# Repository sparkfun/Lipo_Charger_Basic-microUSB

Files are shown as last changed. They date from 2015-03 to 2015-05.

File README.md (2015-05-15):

SparkFun LiPo Charger Basic - Micro-USB
========================================

SparkFun LiPo Charger Basic - Micro-USB

[*SparkFun LiPo Charger Basic - Micro-USB (PRT-10217)*](https://www.sparkfun.com/products/10217)

The SparkFun LiPo Charger Basic is stripped down of all features and just does one thing well - charge 3.7V LiPo cells at a rate of 500mA. 
It is designed to charge single-cell Li-Ion or Li-Polymer batteries. 
The board incorporates a charging circuit, status LED, connector for your battery (JST-type used in the batteries we carry), and a micro-USB connector. 
A small mounting hole allows this charger to be easily embedded into a project.

Repository Contents
-------------------
* **/Hardware** - Eagle design files (.brd, .sch)
* **/Production** - Production panel files (.brd)

Documentation
--------------
* **[SparkFun Fritzing repo](https://github.com/sparkfun/Fritzing_Parts)** - Fritzing diagrams for SparkFun products.
* **[SparkFun 3D Model repo](https://github.com/sparkfun/3D_Models)** - 3D models of SparkFun products. 

License Information
-------------------
This product is _**open source**_! 

The **hardware** is released under [Creative Commons ShareAlike 4.0 International](https://creativecommons.org/licenses/by-sa/4.0/).

Please use, reuse, and modify these files as you see fit. Please maintain attribution to SparkFun Electronics and release anything derivative under the same license.

Distributed as-is; no warranty is given.

- Your friends at SparkFun.

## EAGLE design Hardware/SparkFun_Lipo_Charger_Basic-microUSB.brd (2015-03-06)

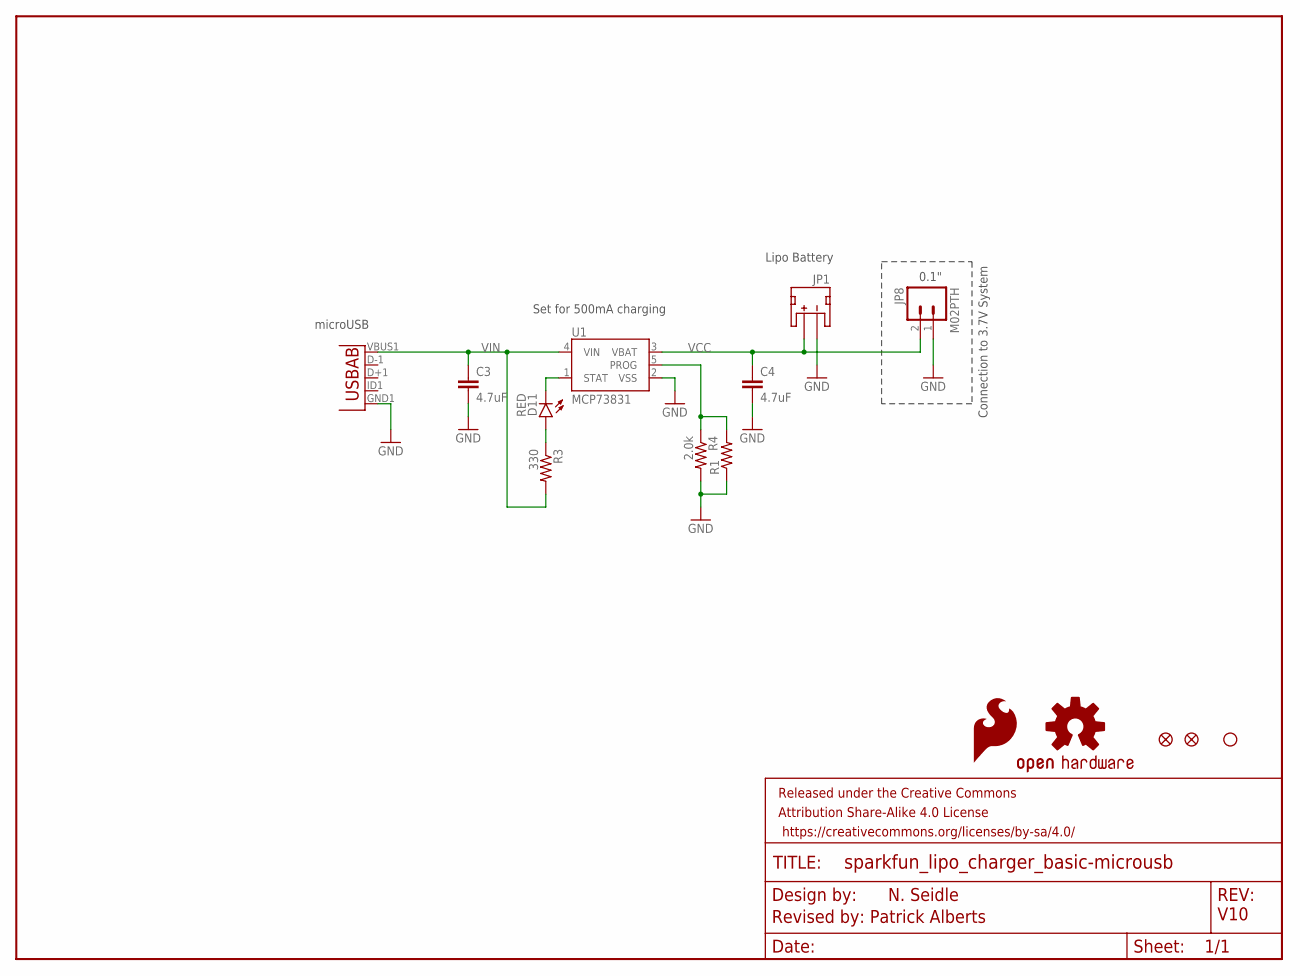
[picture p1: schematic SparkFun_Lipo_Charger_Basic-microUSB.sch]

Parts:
C3, C4: 4.7uF; 0603-CAP
D11: RED; LED-0603
FRAME1: FRAME-LETTER; CREATIVE_COMMONS
JP1: JST; JST-2-SMD
JP2: STAND-OFF
JP3, JP4: FIDUCIAL1X2; FIDUCIAL-1X2
JP8: M02PTH; 1X02
JP9: Micro USB; USB-AB-MICRO-SMD_V03
LOGO1: OSHW-LOGOS; OSHW-LOGO-S
LOGO2: SFE_LOGO_FLAME.1_INCH; SFE_LOGO_FLAME_.1
R1: RESISTORPTH-1/4W-VERT-KIT; AXIAL-0.1EZ
R3: 330; 0603-RES
R4: 2.0k; 0603-RES
U1: MCP73831; SOT23-5

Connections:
GND: C3.2, C4.2, JP1.1 (-), JP8.1, JP9.GND1 (GND), R1.P$1 (1), R4.2, U1.2 (VSS)
unnamed: D11.A, R3.1
PROG: R1.P$2 (2), R4.1, U1.5 (PROG)
STAT: D11.C, U1.1 (STAT)
VCC: C4.1, JP1.2 (+), JP8.2, U1.3 (VBAT)
VIN: C3.1, JP9.VBUS1 (VBUS), R3.2, U1.4 (VIN)

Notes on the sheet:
Set for 500mA charging
Connection to 3.7V System
0.1"
N. Seidle
microUSB
Revised by: Patrick Alberts
V10
Lipo Battery

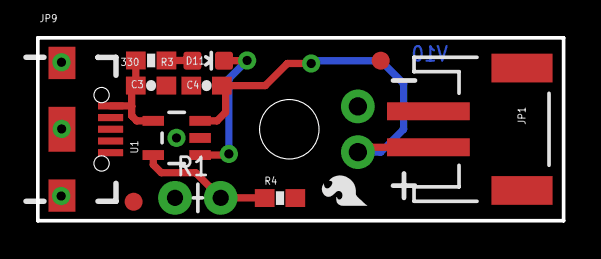
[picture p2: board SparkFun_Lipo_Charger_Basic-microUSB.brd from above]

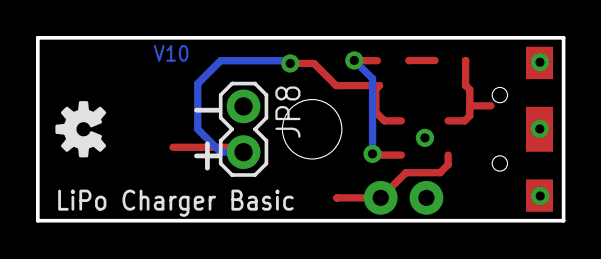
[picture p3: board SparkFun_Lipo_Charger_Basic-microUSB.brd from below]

Board: 2 copper layers, 29.2 x 10.2 mm, 16 parts (2 on the bottom side), 6 nets.

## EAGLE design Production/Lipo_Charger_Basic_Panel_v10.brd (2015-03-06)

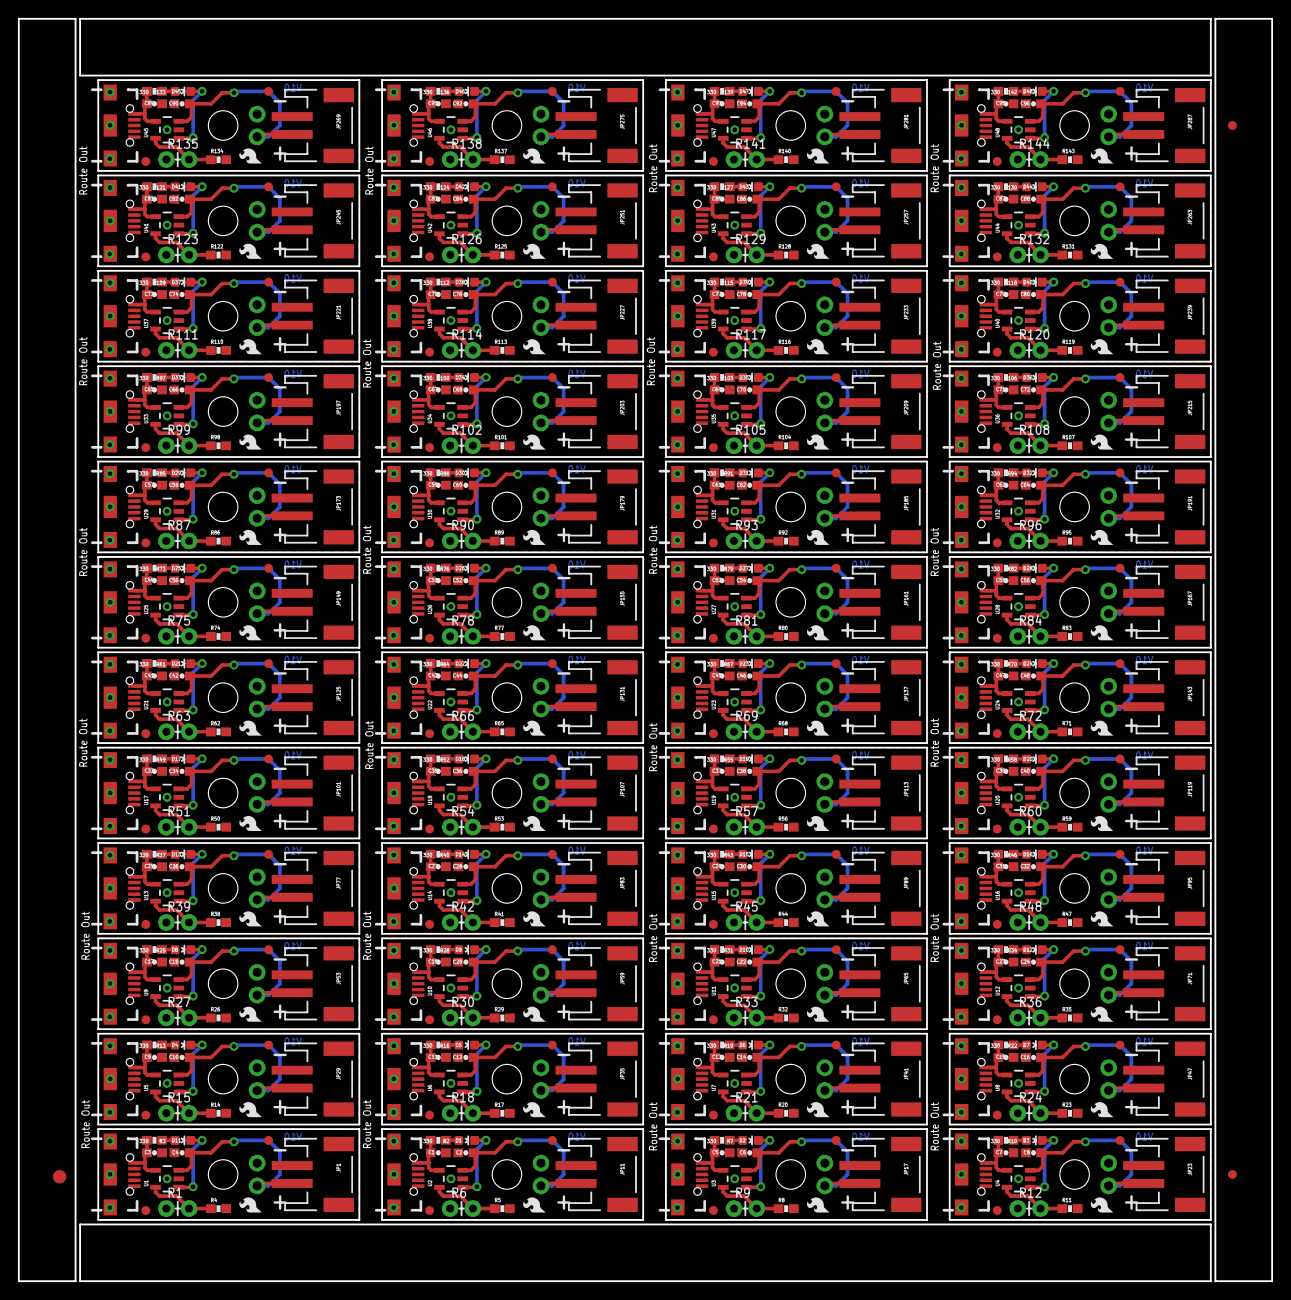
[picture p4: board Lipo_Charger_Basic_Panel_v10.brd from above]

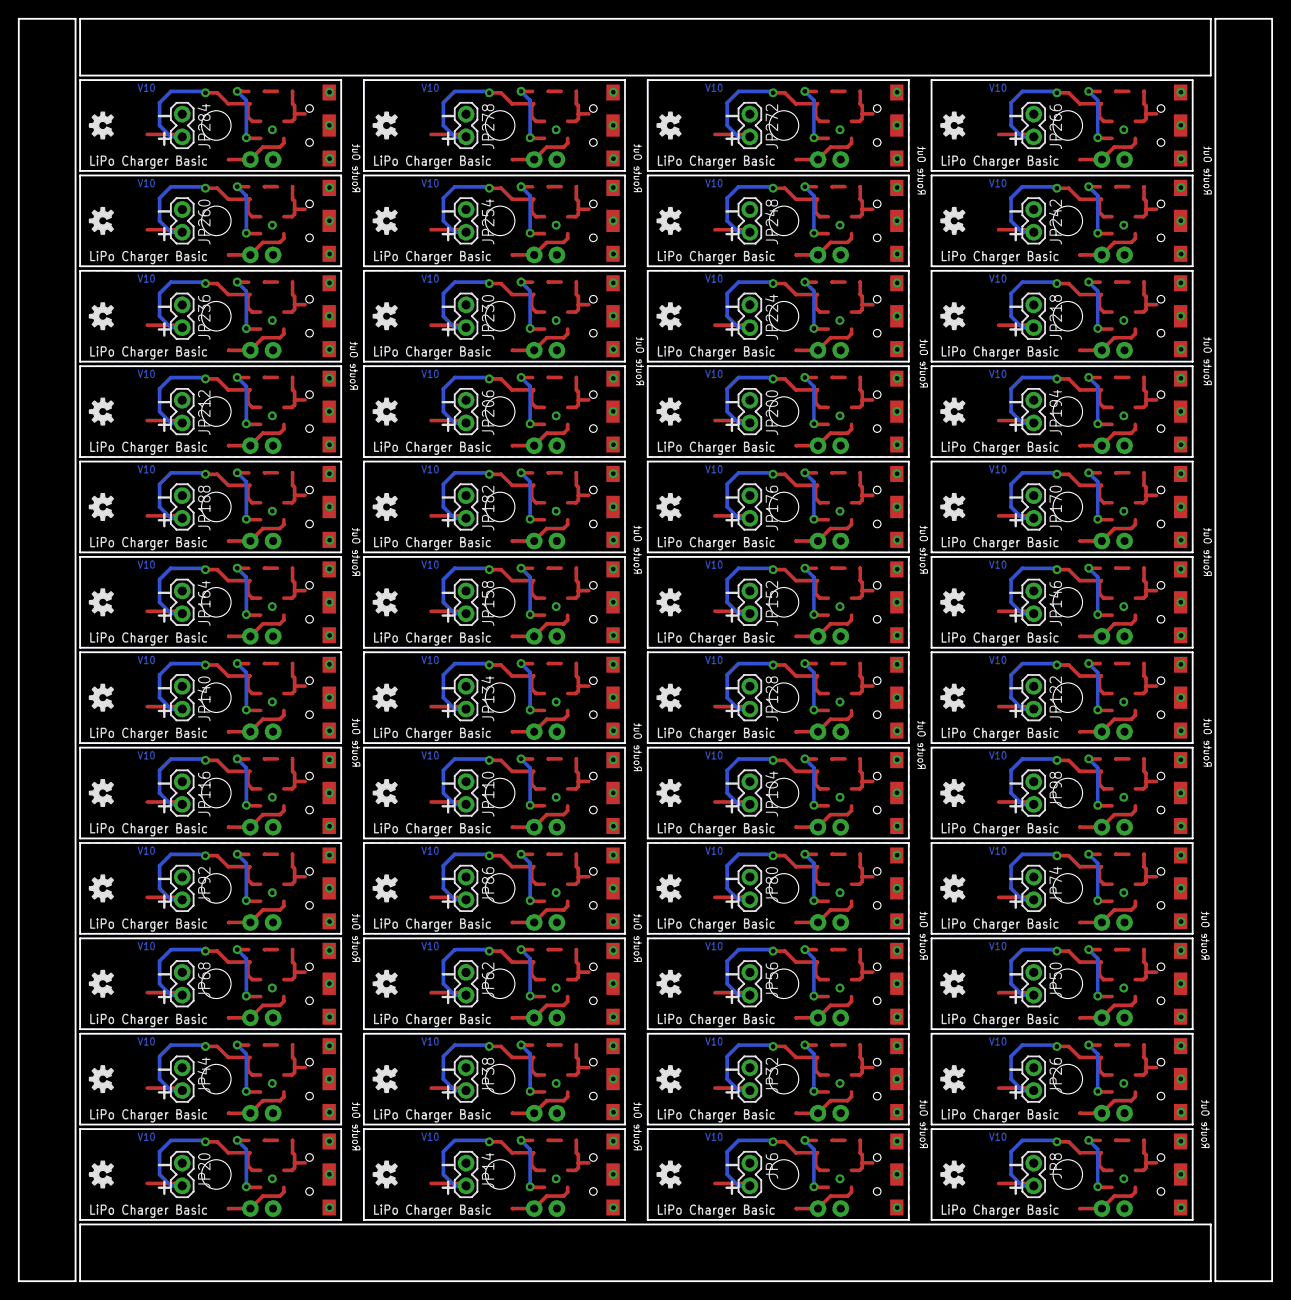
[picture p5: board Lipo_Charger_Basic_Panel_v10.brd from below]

Board: 2 copper layers, 140.2 x 141.2 mm, 723 parts (96 on the bottom side), 288 nets.

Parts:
C1, C2, C3, C4, C5, C6, C7, C8, C9, C10, C11, C12, C13, C14, C15, C16, C17, C18, C19, C20, C21, C22, C23, C24, C25, C26, C27, C28, C29, C30, C31, C32, C33, C34, C35, C36, C37, C38, C39, C40, C41, C42, C43, C44, C45, C46, C47, C48, C49, C50, C51, C52, C53, C54, C55, C56, C57, C58, C59, C60, C61, C62, C63, C64, C65, C66, C67, C68, C69, C70, C71, C72, C73, C74, C75, C76, C77, C78, C79, C80, C81, C82, C83, C84, C85, C86, C87, C88, C89, C90, C91, C92, C93, C94, C95, C96: 4.7uF; 0603-CAP
D1, D2, D3, D4, D5, D6, D7, D8, D9, D10, D11, D12, D13, D14, D15, D16, D17, D18, D19, D20, D21, D22, D23, D24, D25, D26, D27, D28, D29, D30, D31, D32, D33, D34, D35, D36, D37, D38, D39, D40, D41, D42, D43, D44, D45, D46, D47, D48: RED; LED-0603
E$1: FIDUCIAL-1.5X3
E$5, E$6: FIDUCIAL-1X2
JP1, JP11, JP17, JP23, JP29, JP35, JP41, JP47, JP53, JP59, JP65, JP71, JP77, JP83, JP89, JP95, JP101, JP107, JP113, JP119, JP125, JP131, JP137, JP143, JP149, JP155, JP161, JP167, JP173, JP179, JP185, JP191, JP197, JP203, JP209, JP215, JP221, JP227, JP233, JP239, JP245, JP251, JP257, JP263, JP269, JP275, JP281, JP287: JST; JST-2-SMD
JP2, JP5, JP13, JP19, JP25, JP31, JP37, JP43, JP49, JP55, JP61, JP67, JP73, JP79, JP85, JP91, JP97, JP103, JP109, JP115, JP121, JP127, JP133, JP139, JP145, JP151, JP157, JP163, JP169, JP175, JP181, JP187, JP193, JP199, JP205, JP211, JP217, JP223, JP229, JP235, JP241, JP247, JP253, JP259, JP265, JP271, JP277, JP283: STAND-OFF
JP3, JP4, JP10, JP12, JP16, JP18, JP22, JP24, JP28, JP30, JP34, JP36, JP40, JP42, JP46, JP48, JP52, JP54, JP58, JP60, JP64, JP66, JP70, JP72, JP76, JP78, JP82, JP84, JP88, JP90, JP94, JP96, JP100, JP102, JP106, JP108, JP112, JP114, JP118, JP120, JP124, JP126, JP130, JP132, JP136, JP138, JP142, JP144, JP148, JP150, JP154, JP156, JP160, JP162, JP166, JP168, JP172, JP174, JP178, JP180, JP184, JP186, JP190, JP192, JP196, JP198, JP202, JP204, JP208, JP210, JP214, JP216, JP220, JP222, JP226, JP228, JP232, JP234, JP238, JP240, JP244, JP246, JP250, JP252, JP256, JP258, JP262, JP264, JP268, JP270, JP274, JP276, JP280, JP282, JP286, JP288: FIDUCIAL1X2; FIDUCIAL-1X2
JP6, JP8, JP14, JP20, JP26, JP32, JP38, JP44, JP50, JP56, JP62, JP68, JP74, JP80, JP86, JP92, JP98, JP104, JP110, JP116, JP122, JP128, JP134, JP140, JP146, JP152, JP158, JP164, JP170, JP176, JP182, JP188, JP194, JP200, JP206, JP212, JP218, JP224, JP230, JP236, JP242, JP248, JP254, JP260, JP266, JP272, JP278, JP284: M02PTH; 1X02
JP7, JP9, JP15, JP21, JP27, JP33, JP39, JP45, JP51, JP57, JP63, JP69, JP75, JP81, JP87, JP93, JP99, JP105, JP111, JP117, JP123, JP129, JP135, JP141, JP147, JP153, JP159, JP165, JP171, JP177, JP183, JP189, JP195, JP201, JP207, JP213, JP219, JP225, JP231, JP237, JP243, JP249, JP255, JP261, JP267, JP273, JP279, JP285: Micro USB; USB-AB-MICRO-SMD_V03
LOGO1, LOGO3, LOGO5, LOGO7, LOGO9, LOGO11, LOGO13, LOGO15, LOGO17, LOGO19, LOGO21, LOGO23, LOGO25, LOGO27, LOGO29, LOGO31, LOGO33, LOGO35, LOGO37, LOGO39, LOGO41, LOGO43, LOGO45, LOGO47, LOGO49, LOGO51, LOGO53, LOGO55, LOGO57, LOGO59, LOGO61, LOGO63, LOGO65, LOGO67, LOGO69, LOGO71, LOGO73, LOGO75, LOGO77, LOGO79, LOGO81, LOGO83, LOGO85, LOGO87, LOGO89, LOGO91, LOGO93, LOGO95: OSHW-LOGOS; OSHW-LOGO-S
LOGO2, LOGO4, LOGO6, LOGO8, LOGO10, LOGO12, LOGO14, LOGO16, LOGO18, LOGO20, LOGO22, LOGO24, LOGO26, LOGO28, LOGO30, LOGO32, LOGO34, LOGO36, LOGO38, LOGO40, LOGO42, LOGO44, LOGO46, LOGO48, LOGO50, LOGO52, LOGO54, LOGO56, LOGO58, LOGO60, LOGO62, LOGO64, LOGO66, LOGO68, LOGO70, LOGO72, LOGO74, LOGO76, LOGO78, LOGO80, LOGO82, LOGO84, LOGO86, LOGO88, LOGO90, LOGO92, LOGO94, LOGO96: SFE_LOGO_FLAME.1_INCH; SFE_LOGO_FLAME_.1
R1, R6, R9, R12, R15, R18, R21, R24, R27, R30, R33, R36, R39, R42, R45, R48, R51, R54, R57, R60, R63, R66, R69, R72, R75, R78, R81, R84, R87, R90, R93, R96, R99, R102, R105, R108, R111, R114, R117, R120, R123, R126, R129, R132, R135, R138, R141, R144: AXIAL-0.1EZ
R2, R3, R7, R10, R13, R16, R19, R22, R25, R28, R31, R34, R37, R40, R43, R46, R49, R52, R55, R58, R61, R64, R67, R70, R73, R76, R79, R82, R85, R88, R91, R94, R97, R100, R103, R106, R109, R112, R115, R118, R121, R124, R127, R130, R133, R136, R139, R142: 330; 0603-RES
R4, R5, R8, R11, R14, R17, R20, R23, R26, R29, R32, R35, R38, R41, R44, R47, R50, R53, R56, R59, R62, R65, R68, R71, R74, R77, R80, R83, R86, R89, R92, R95, R98, R101, R104, R107, R110, R113, R116, R119, R122, R125, R128, R131, R134, R137, R140, R143: 2.0k; 0603-RES
U1, U2, U3, U4, U5, U6, U7, U8, U9, U10, U11, U12, U13, U14, U15, U16, U17, U18, U19, U20, U21, U22, U23, U24, U25, U26, U27, U28, U29, U30, U31, U32, U33, U34, U35, U36, U37, U38, U39, U40, U41, U42, U43, U44, U45, U46, U47, U48: MCP73831; SOT23-5

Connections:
GND: C3.2, C4.2, JP1.1, JP8.1, JP9.GND1, R1.P$1, R4.2, U1.2
GND1: C1.2, C2.2, JP6.1, JP7.GND1, JP11.1, R5.2, R6.P$1, U2.2
GND2: C5.2, C6.2, JP14.1, JP15.GND1, JP17.1, R8.2, R9.P$1, U3.2
GND3: C7.2, C8.2, JP20.1, JP21.GND1, JP23.1, R11.2, R12.P$1, U4.2
GND4: C9.2, C10.2, JP26.1, JP27.GND1, JP29.1, R14.2, R15.P$1, U5.2
GND5: C11.2, C12.2, JP32.1, JP33.GND1, JP35.1, R17.2, R18.P$1, U6.2
GND6: C13.2, C14.2, JP38.1, JP39.GND1, JP41.1, R20.2, R21.P$1, U7.2
GND7: C15.2, C16.2, JP44.1, JP45.GND1, JP47.1, R23.2, R24.P$1, U8.2
GND8: C17.2, C18.2, JP50.1, JP51.GND1, JP53.1, R26.2, R27.P$1, U9.2
GND9: C19.2, C20.2, JP56.1, JP57.GND1, JP59.1, R29.2, R30.P$1, U10.2
GND10: C21.2, C22.2, JP62.1, JP63.GND1, JP65.1, R32.2, R33.P$1, U11.2
GND11: C23.2, C24.2, JP68.1, JP69.GND1, JP71.1, R35.2, R36.P$1, U12.2
GND12: C25.2, C26.2, JP74.1, JP75.GND1, JP77.1, R38.2, R39.P$1, U13.2
GND13: C27.2, C28.2, JP80.1, JP81.GND1, JP83.1, R41.2, R42.P$1, U14.2
GND14: C29.2, C30.2, JP86.1, JP87.GND1, JP89.1, R44.2, R45.P$1, U15.2
GND15: C31.2, C32.2, JP92.1, JP93.GND1, JP95.1, R47.2, R48.P$1, U16.2
GND16: C33.2, C34.2, JP98.1, JP99.GND1, JP101.1, R50.2, R51.P$1, U17.2
GND17: C35.2, C36.2, JP104.1, JP105.GND1, JP107.1, R53.2, R54.P$1, U18.2
GND18: C37.2, C38.2, JP110.1, JP111.GND1, JP113.1, R56.2, R57.P$1, U19.2
GND19: C39.2, C40.2, JP116.1, JP117.GND1, JP119.1, R59.2, R60.P$1, U20.2
GND20: C41.2, C42.2, JP122.1, JP123.GND1, JP125.1, R62.2, R63.P$1, U21.2
GND21: C43.2, C44.2, JP128.1, JP129.GND1, JP131.1, R65.2, R66.P$1, U22.2
GND22: C45.2, C46.2, JP134.1, JP135.GND1, JP137.1, R68.2, R69.P$1, U23.2
GND23: C47.2, C48.2, JP140.1, JP141.GND1, JP143.1, R71.2, R72.P$1, U24.2
GND24: C49.2, C50.2, JP146.1, JP147.GND1, JP149.1, R74.2, R75.P$1, U25.2
GND25: C51.2, C52.2, JP152.1, JP153.GND1, JP155.1, R77.2, R78.P$1, U26.2
GND26: C53.2, C54.2, JP158.1, JP159.GND1, JP161.1, R80.2, R81.P$1, U27.2
GND27: C55.2, C56.2, JP164.1, JP165.GND1, JP167.1, R83.2, R84.P$1, U28.2
GND28: C57.2, C58.2, JP170.1, JP171.GND1, JP173.1, R86.2, R87.P$1, U29.2
GND29: C59.2, C60.2, JP176.1, JP177.GND1, JP179.1, R89.2, R90.P$1, U30.2
GND30: C61.2, C62.2, JP182.1, JP183.GND1, JP185.1, R92.2, R93.P$1, U31.2
GND31: C63.2, C64.2, JP188.1, JP189.GND1, JP191.1, R95.2, R96.P$1, U32.2
GND32: C65.2, C66.2, JP194.1, JP195.GND1, JP197.1, R98.2, R99.P$1, U33.2
GND33: C67.2, C68.2, JP200.1, JP201.GND1, JP203.1, R101.2, R102.P$1, U34.2
GND34: C69.2, C70.2, JP206.1, JP207.GND1, JP209.1, R104.2, R105.P$1, U35.2
GND35: C71.2, C72.2, JP212.1, JP213.GND1, JP215.1, R107.2, R108.P$1, U36.2
GND36: C73.2, C74.2, JP218.1, JP219.GND1, JP221.1, R110.2, R111.P$1, U37.2
GND37: C75.2, C76.2, JP224.1, JP225.GND1, JP227.1, R113.2, R114.P$1, U38.2
GND38: C77.2, C78.2, JP230.1, JP231.GND1, JP233.1, R116.2, R117.P$1, U39.2
GND39: C79.2, C80.2, JP236.1, JP237.GND1, JP239.1, R119.2, R120.P$1, U40.2
GND40: C81.2, C82.2, JP242.1, JP243.GND1, JP245.1, R122.2, R123.P$1, U41.2
GND41: C83.2, C84.2, JP248.1, JP249.GND1, JP251.1, R125.2, R126.P$1, U42.2
GND42: C85.2, C86.2, JP254.1, JP255.GND1, JP257.1, R128.2, R129.P$1, U43.2
GND43: C87.2, C88.2, JP260.1, JP261.GND1, JP263.1, R131.2, R132.P$1, U44.2
GND44: C89.2, C90.2, JP266.1, JP267.GND1, JP269.1, R134.2, R135.P$1, U45.2
GND45: C91.2, C92.2, JP272.1, JP273.GND1, JP275.1, R137.2, R138.P$1, U46.2
GND46: C93.2, C94.2, JP278.1, JP279.GND1, JP281.1, R140.2, R141.P$1, U47.2
GND47: C95.2, C96.2, JP284.1, JP285.GND1, JP287.1, R143.2, R144.P$1, U48.2
unnamed: D1.A, R2.1
unnamed: D2.A, R7.1
unnamed: D11.A, R3.1
unnamed: D3.A, R10.1
unnamed: D4.A, R13.1
unnamed: D5.A, R16.1
unnamed: D6.A, R19.1
unnamed: D7.A, R22.1
unnamed: D8.A, R25.1
unnamed: D9.A, R28.1
unnamed: D10.A, R31.1
unnamed: D12.A, R34.1
unnamed: D13.A, R37.1
unnamed: D14.A, R40.1
unnamed: D15.A, R43.1
unnamed: D16.A, R46.1
unnamed: D17.A, R49.1
unnamed: D18.A, R52.1
unnamed: D19.A, R55.1
unnamed: D20.A, R58.1
unnamed: D21.A, R61.1
unnamed: D22.A, R64.1
unnamed: D23.A, R67.1
unnamed: D24.A, R70.1
unnamed: D25.A, R73.1
unnamed: D26.A, R76.1
unnamed: D27.A, R79.1
unnamed: D28.A, R82.1
unnamed: D29.A, R85.1
unnamed: D30.A, R88.1
unnamed: D31.A, R91.1
unnamed: D32.A, R94.1
unnamed: D33.A, R97.1
unnamed: D34.A, R100.1
unnamed: D35.A, R103.1
unnamed: D36.A, R106.1
unnamed: D37.A, R109.1
unnamed: D38.A, R112.1
unnamed: D39.A, R115.1
unnamed: D40.A, R118.1
unnamed: D41.A, R121.1
unnamed: D42.A, R124.1
unnamed: D43.A, R127.1
unnamed: D44.A, R130.1
unnamed: D45.A, R133.1
unnamed: D46.A, R136.1
unnamed: D47.A, R139.1
unnamed: D48.A, R142.1
PROG: R1.P$2, R4.1, U1.5
PROG1: R5.1, R6.P$2, U2.5
PROG2: R8.1, R9.P$2, U3.5
PROG3: R11.1, R12.P$2, U4.5
PROG4: R14.1, R15.P$2, U5.5
PROG5: R17.1, R18.P$2, U6.5
PROG6: R20.1, R21.P$2, U7.5
PROG7: R23.1, R24.P$2, U8.5
PROG8: R26.1, R27.P$2, U9.5
PROG9: R29.1, R30.P$2, U10.5
PROG10: R32.1, R33.P$2, U11.5
PROG11: R35.1, R36.P$2, U12.5
PROG12: R38.1, R39.P$2, U13.5
PROG13: R41.1, R42.P$2, U14.5
PROG14: R44.1, R45.P$2, U15.5
PROG15: R47.1, R48.P$2, U16.5
PROG16: R50.1, R51.P$2, U17.5
PROG17: R53.1, R54.P$2, U18.5
PROG18: R56.1, R57.P$2, U19.5
PROG19: R59.1, R60.P$2, U20.5
PROG20: R62.1, R63.P$2, U21.5
PROG21: R65.1, R66.P$2, U22.5
PROG22: R68.1, R69.P$2, U23.5
PROG23: R71.1, R72.P$2, U24.5
PROG24: R74.1, R75.P$2, U25.5
PROG25: R77.1, R78.P$2, U26.5
PROG26: R80.1, R81.P$2, U27.5
PROG27: R83.1, R84.P$2, U28.5
PROG28: R86.1, R87.P$2, U29.5
PROG29: R89.1, R90.P$2, U30.5
PROG30: R92.1, R93.P$2, U31.5
PROG31: R95.1, R96.P$2, U32.5
PROG32: R98.1, R99.P$2, U33.5
PROG33: R101.1, R102.P$2, U34.5
PROG34: R104.1, R105.P$2, U35.5
PROG35: R107.1, R108.P$2, U36.5
PROG36: R110.1, R111.P$2, U37.5
PROG37: R113.1, R114.P$2, U38.5
PROG38: R116.1, R117.P$2, U39.5
PROG39: R119.1, R120.P$2, U40.5
PROG40: R122.1, R123.P$2, U41.5
PROG41: R125.1, R126.P$2, U42.5
PROG42: R128.1, R129.P$2, U43.5
PROG43: R131.1, R132.P$2, U44.5
PROG44: R134.1, R135.P$2, U45.5
PROG45: R137.1, R138.P$2, U46.5
PROG46: R140.1, R141.P$2, U47.5
PROG47: R143.1, R144.P$2, U48.5
STAT: D11.C, U1.1
STAT1: D1.C, U2.1
STAT2: D2.C, U3.1
STAT3: D3.C, U4.1
STAT4: D4.C, U5.1
STAT5: D5.C, U6.1
STAT6: D6.C, U7.1
STAT7: D7.C, U8.1
STAT8: D8.C, U9.1
STAT9: D9.C, U10.1
STAT10: D10.C, U11.1
STAT11: D12.C, U12.1
STAT12: D13.C, U13.1
STAT13: D14.C, U14.1
STAT14: D15.C, U15.1
STAT15: D16.C, U16.1
STAT16: D17.C, U17.1
STAT17: D18.C, U18.1
STAT18: D19.C, U19.1
STAT19: D20.C, U20.1
STAT20: D21.C, U21.1
STAT21: D22.C, U22.1
STAT22: D23.C, U23.1
STAT23: D24.C, U24.1
STAT24: D25.C, U25.1
STAT25: D26.C, U26.1
STAT26: D27.C, U27.1
STAT27: D28.C, U28.1
STAT28: D29.C, U29.1
STAT29: D30.C, U30.1
STAT30: D31.C, U31.1
STAT31: D32.C, U32.1
STAT32: D33.C, U33.1
STAT33: D34.C, U34.1
STAT34: D35.C, U35.1
STAT35: D36.C, U36.1
STAT36: D37.C, U37.1
STAT37: D38.C, U38.1
STAT38: D39.C, U39.1
STAT39: D40.C, U40.1
STAT40: D41.C, U41.1
STAT41: D42.C, U42.1
STAT42: D43.C, U43.1
STAT43: D44.C, U44.1
STAT44: D45.C, U45.1
STAT45: D46.C, U46.1
STAT46: D47.C, U47.1
STAT47: D48.C, U48.1
VCC: C4.1, JP1.2, JP8.2, U1.3
VCC1: C2.1, JP6.2, JP11.2, U2.3
VCC2: C6.1, JP14.2, JP17.2, U3.3
VCC3: C8.1, JP20.2, JP23.2, U4.3
VCC4: C10.1, JP26.2, JP29.2, U5.3
VCC5: C12.1, JP32.2, JP35.2, U6.3
VCC6: C14.1, JP38.2, JP41.2, U7.3
VCC7: C16.1, JP44.2, JP47.2, U8.3
VCC8: C18.1, JP50.2, JP53.2, U9.3
VCC9: C20.1, JP56.2, JP59.2, U10.3
VCC10: C22.1, JP62.2, JP65.2, U11.3
VCC11: C24.1, JP68.2, JP71.2, U12.3
VCC12: C26.1, JP74.2, JP77.2, U13.3
VCC13: C28.1, JP80.2, JP83.2, U14.3
VCC14: C30.1, JP86.2, JP89.2, U15.3
VCC15: C32.1, JP92.2, JP95.2, U16.3
VCC16: C34.1, JP98.2, JP101.2, U17.3
VCC17: C36.1, JP104.2, JP107.2, U18.3
VCC18: C38.1, JP110.2, JP113.2, U19.3
VCC19: C40.1, JP116.2, JP119.2, U20.3
VCC20: C42.1, JP122.2, JP125.2, U21.3
VCC21: C44.1, JP128.2, JP131.2, U22.3
VCC22: C46.1, JP134.2, JP137.2, U23.3
VCC23: C48.1, JP140.2, JP143.2, U24.3
VCC24: C50.1, JP146.2, JP149.2, U25.3
VCC25: C52.1, JP152.2, JP155.2, U26.3
VCC26: C54.1, JP158.2, JP161.2, U27.3
VCC27: C56.1, JP164.2, JP167.2, U28.3
VCC28: C58.1, JP170.2, JP173.2, U29.3
VCC29: C60.1, JP176.2, JP179.2, U30.3
VCC30: C62.1, JP182.2, JP185.2, U31.3
VCC31: C64.1, JP188.2, JP191.2, U32.3
VCC32: C66.1, JP194.2, JP197.2, U33.3
VCC33: C68.1, JP200.2, JP203.2, U34.3
VCC34: C70.1, JP206.2, JP209.2, U35.3
VCC35: C72.1, JP212.2, JP215.2, U36.3
VCC36: C74.1, JP218.2, JP221.2, U37.3
VCC37: C76.1, JP224.2, JP227.2, U38.3
VCC38: C78.1, JP230.2, JP233.2, U39.3
VCC39: C80.1, JP236.2, JP239.2, U40.3
VCC40: C82.1, JP242.2, JP245.2, U41.3
VCC41: C84.1, JP248.2, JP251.2, U42.3
VCC42: C86.1, JP254.2, JP257.2, U43.3
VCC43: C88.1, JP260.2, JP263.2, U44.3
VCC44: C90.1, JP266.2, JP269.2, U45.3
VCC45: C92.1, JP272.2, JP275.2, U46.3
VCC46: C94.1, JP278.2, JP281.2, U47.3
VCC47: C96.1, JP284.2, JP287.2, U48.3
VIN: C3.1, JP9.VBUS1, R3.2, U1.4
VIN1: C1.1, JP7.VBUS1, R2.2, U2.4
VIN2: C5.1, JP15.VBUS1, R7.2, U3.4
VIN3: C7.1, JP21.VBUS1, R10.2, U4.4
VIN4: C9.1, JP27.VBUS1, R13.2, U5.4
VIN5: C11.1, JP33.VBUS1, R16.2, U6.4
VIN6: C13.1, JP39.VBUS1, R19.2, U7.4
VIN7: C15.1, JP45.VBUS1, R22.2, U8.4
VIN8: C17.1, JP51.VBUS1, R25.2, U9.4
VIN9: C19.1, JP57.VBUS1, R28.2, U10.4
VIN10: C21.1, JP63.VBUS1, R31.2, U11.4
VIN11: C23.1, JP69.VBUS1, R34.2, U12.4
VIN12: C25.1, JP75.VBUS1, R37.2, U13.4
VIN13: C27.1, JP81.VBUS1, R40.2, U14.4
VIN14: C29.1, JP87.VBUS1, R43.2, U15.4
VIN15: C31.1, JP93.VBUS1, R46.2, U16.4
VIN16: C33.1, JP99.VBUS1, R49.2, U17.4
VIN17: C35.1, JP105.VBUS1, R52.2, U18.4
VIN18: C37.1, JP111.VBUS1, R55.2, U19.4
VIN19: C39.1, JP117.VBUS1, R58.2, U20.4
VIN20: C41.1, JP123.VBUS1, R61.2, U21.4
VIN21: C43.1, JP129.VBUS1, R64.2, U22.4
VIN22: C45.1, JP135.VBUS1, R67.2, U23.4
VIN23: C47.1, JP141.VBUS1, R70.2, U24.4
VIN24: C49.1, JP147.VBUS1, R73.2, U25.4
VIN25: C51.1, JP153.VBUS1, R76.2, U26.4
VIN26: C53.1, JP159.VBUS1, R79.2, U27.4
VIN27: C55.1, JP165.VBUS1, R82.2, U28.4
VIN28: C57.1, JP171.VBUS1, R85.2, U29.4
VIN29: C59.1, JP177.VBUS1, R88.2, U30.4
VIN30: C61.1, JP183.VBUS1, R91.2, U31.4
VIN31: C63.1, JP189.VBUS1, R94.2, U32.4
VIN32: C65.1, JP195.VBUS1, R97.2, U33.4
VIN33: C67.1, JP201.VBUS1, R100.2, U34.4
VIN34: C69.1, JP207.VBUS1, R103.2, U35.4
VIN35: C71.1, JP213.VBUS1, R106.2, U36.4
VIN36: C73.1, JP219.VBUS1, R109.2, U37.4
VIN37: C75.1, JP225.VBUS1, R112.2, U38.4
VIN38: C77.1, JP231.VBUS1, R115.2, U39.4
VIN39: C79.1, JP237.VBUS1, R118.2, U40.4
VIN40: C81.1, JP243.VBUS1, R121.2, U41.4
VIN41: C83.1, JP249.VBUS1, R124.2, U42.4
VIN42: C85.1, JP255.VBUS1, R127.2, U43.4
VIN43: C87.1, JP261.VBUS1, R130.2, U44.4
VIN44: C89.1, JP267.VBUS1, R133.2, U45.4
VIN45: C91.1, JP273.VBUS1, R136.2, U46.4
VIN46: C93.1, JP279.VBUS1, R139.2, U47.4
VIN47: C95.1, JP285.VBUS1, R142.2, U48.4

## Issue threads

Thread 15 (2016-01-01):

How does one "read" the status led?

Bazmundi, 2016-01-01:
How do I tell the difference between charged, charging and discharged using the LED?

Bazmundi, 2016-01-01:
Cheers, I poked through the specs for the chip and had a look at the schematic.  STATUS goes HI when charged so LED goes out si!?

bboyho, 2020-05-22:
Hi,

Sorry for the delay in reply. I just noticed your question when browsing the issues. This is a common question when using the MCP73831T. You are correct. When the battery is charge, the LED will turn off. If you are still wondering what this stat LED does, check below:

If you look at the datasheet for the LiPo USB Charger's IC controller, the LED is connected to the charge status output (STAT). This is an output to indicate the charge status which is explained in section 5.2.1 in table 5-1:

    Shutdown: Hi-Z (High-impedence mode)
    No battery present: Hi-Z
    Preconditioning: L (Low)
    Constant-Current Fast Charge: L
    Constant Voltage: L
    Charge Complete – Standby: H (High)

Since the cathode (-) of the LED is connected to the controller, setting the pin low turns the LED on; setting the pin high (or putting it in high-impedence mode) turns the LED off. From the datasheet, this unit features “AutomaticPower-Down."

Therefore, when the battery is fully **charged**, the LED should turn off and the charge IC controller should turn off.  When the battery is **discharging ** to a load, the LED will be off. When the **charging** a battery and it is **discharging** to a load, the LED will be on as long as the charge IC recognizes the battery as not fully charged. This can fluctuate back and forth with charging depending on if there is some small discharge with the LiPo battery/load.

Closed 2020-05-22.

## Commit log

2014-10-28 Initial commit with brd/sch files
    [Lipo_Charger_Basic.brd, Lipo_Charger_Basic.sch]
2014-10-28 Updated to 0603/Frame/Dimension change
    Updates all components to 0603
    Sch to Frame letter
    Added oshw logo
    minor re routing
    Updated microb to bossed version
    [Lipo_Charger_Basic.brd, Lipo_Charger_Basic.sch]
2015-01-08 Fixed sch and moved micro B
    [Lipo_Charger_Basic.brd, Lipo_Charger_Basic.sch]
2015-01-14 Computer Change update.
    [Lipo_Charger_Basic.brd, Lipo_Charger_Basic.sch]
2015-01-26 qc checklist issues fixed.
    [Lipo_Charger_Basic.brd, Lipo_Charger_Basic.sch]
2015-01-27 Fixed final qc checklist issues
    [Lipo_Charger_Basic.brd, Lipo_Charger_Basic.sch]
2015-02-17 Fixed silk issue, changed rev #'s for reds
    [Lipo_Charger_Basic.brd, Lipo_Charger_Basic.sch]
2015-03-06 qc cl items fixed
    [Lipo_Charger_Basic.brd, Lipo_Charger_Basic.sch]
2015-03-06 created panel v10
    [Lipo_Charger_Basic_Panel_v10.brd]
2015-05-15 Updating directory structure, fixing README
    [Lipo_Charger_Basic_Panel_v10.brd, SparkFun_Lipo_Charger_Basic-microUSB.brd, SparkFun_Lipo_Charger_Basic-microUSB.sch]

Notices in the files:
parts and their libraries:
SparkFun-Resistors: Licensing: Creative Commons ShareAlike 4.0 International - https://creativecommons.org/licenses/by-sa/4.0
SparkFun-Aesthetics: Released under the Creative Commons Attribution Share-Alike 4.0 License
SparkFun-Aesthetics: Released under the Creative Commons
